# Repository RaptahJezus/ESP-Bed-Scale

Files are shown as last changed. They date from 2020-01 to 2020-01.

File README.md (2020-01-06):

ESP Powered Bed Occupancy Sensor

Uses HX711 chip and 4 load cells 

[Load Cells + HX711](https://www.ebay.com/itm/4pcs-50KG-Body-Load-Cell-Resistance-Strain-Weight-Sensor-HX711-AD-Module/182899653153)

Note: Load cells require a bracket that supports the edge, while allowing the middle portion to deflect. Included is "half_bridge_load_sensor_holder-original.stl" which can be 3D printed. I used ABS plastic for mine and it works well.

Load cell bracket design courtesy of linorics on [Thingverse](https://www.thingiverse.com/thing:2486831).

Set up WiFi and MQTT settings in Firmware/include/config.h. Example file is included

Programmed using VSCode + PlatformIO. Schematic designed in EagleCAD

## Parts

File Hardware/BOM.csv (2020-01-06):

Qty | Value | Part Num | Package | Parts
2 |  | * | B3F-10XX | PROG, RES
1 |  | * | ESP8266-ESP12E | MDL1
1 |  | * | 1X02 | VIN
1 |  | * | 1X05 | PANEL
1 | 1uF | * | C0805 | C3
6 | 10K | * | R0805 | R1, R2, R3, R4, R5, R7
1 | 10uF | * | C0805 | C5
1 | 100uf | * | C0805 | C1
1 | 100uf | * | E2,5-6E | C2
2 | 220 | * | R0805 | R8, R9
1 | 470 | * | R0805 | R6
1 | 470pF | * | C0805 | C4
1 | FTDI | * | 1X06 | JP6
1 | HX711-BREAKOUT | * | HX711-THT | U3
1 | LL | * | 1X03 | JP4
1 | LR | * | 1X03 | JP5
1 | MMBT3906 | * | TO92D | Q1
1 | SPX3819M5-L-3-3 | * | SOT23-5L | U2
1 | UL | * | 1X03 | JP2
1 | UR | * | 1X03 | JP3

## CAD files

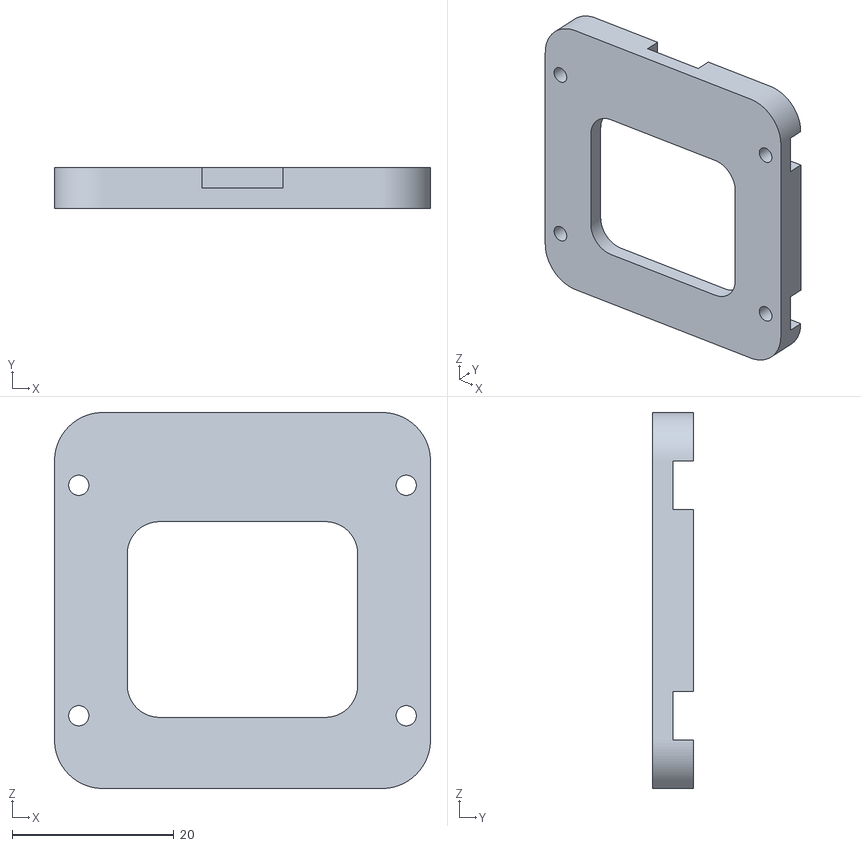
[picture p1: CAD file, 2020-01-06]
Hardware/half_bridge_load_sensor_holder-original.stl
46.5 x 5.04 x 46.5

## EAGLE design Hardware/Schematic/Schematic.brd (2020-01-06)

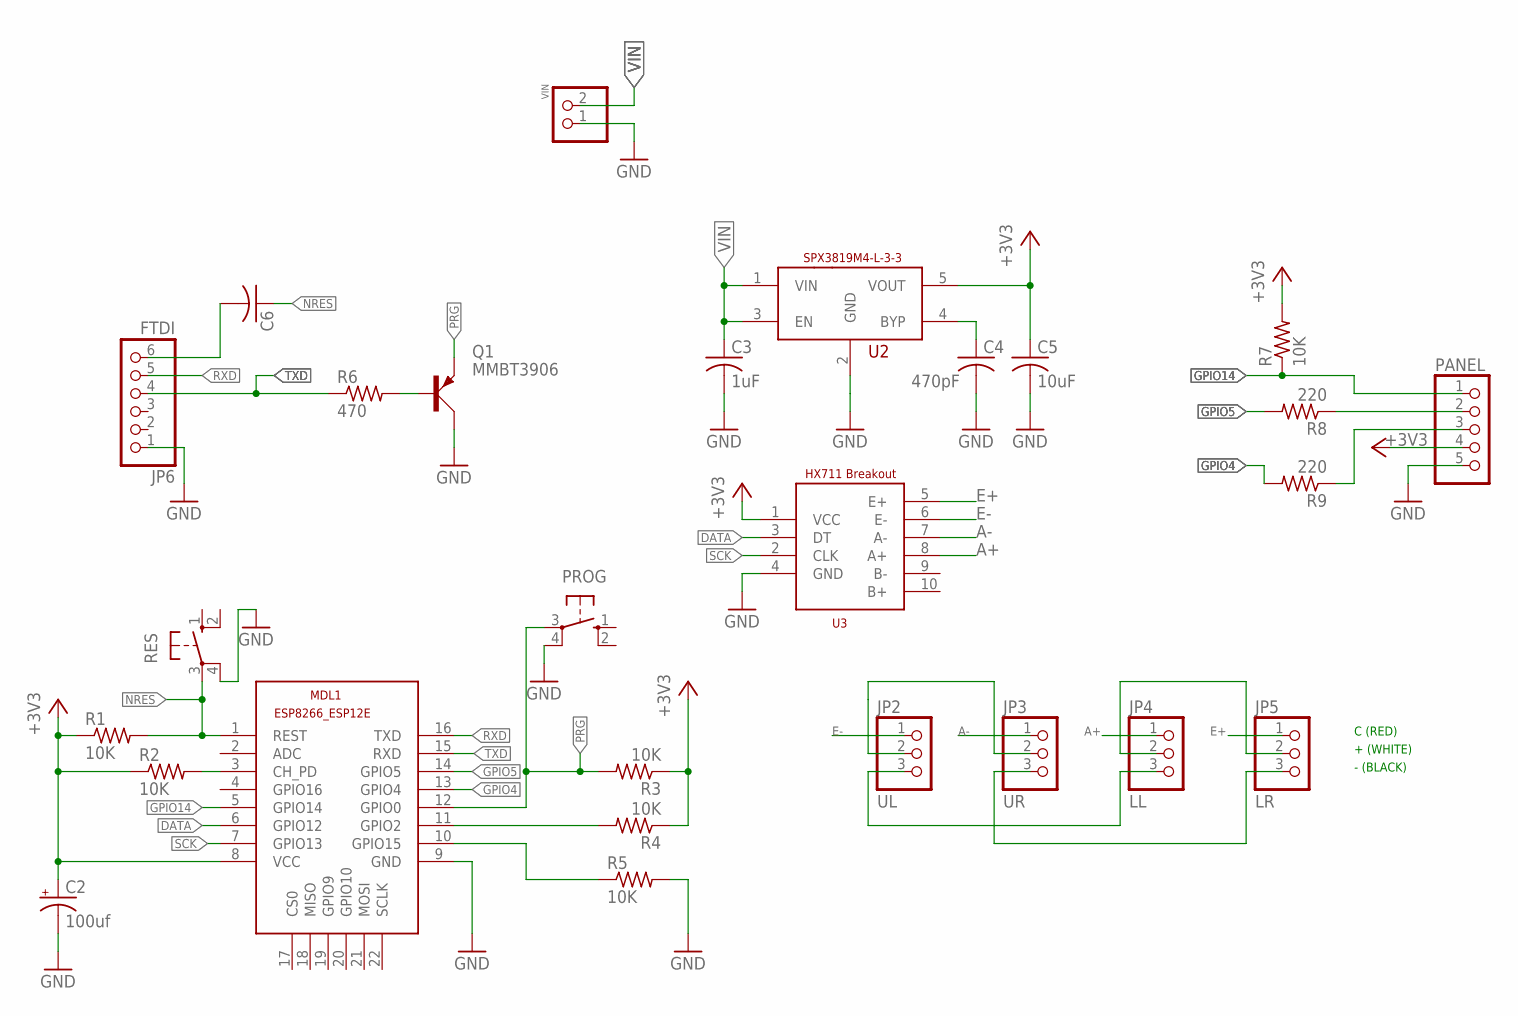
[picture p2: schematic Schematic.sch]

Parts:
C2: 100uf; E2,5-6E
C3: 1uF; C0805
C4: 470pF; C0805
C5: 10uF; C0805
C6: 100uF; C025-024X044
JP2: UL; 1X03
JP3: UR; 1X03
JP4: LL; 1X03
JP5: LR; 1X03
JP6: FTDI; 1X06
MDL1: ESP8266-12EESP8266-ESP12E; ESP8266-ESP12E
PANEL: PINHD-1X5; 1X05
PROG: 10-XX; B3F-10XX
Q1: MMBT3906; TO92D
R1, R2, R3, R4, R5, R7: 10K; R0805
R6: 470; R0805
R8, R9: 220; R0805
RES: 10-XX; B3F-10XX
U2: SPX3819M5-L-3-3; SOT23-5L
U3: HX711-BREAKOUT; HX711-THT
VIN: PINHD-1X2; 1X02

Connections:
+3V3: C2.+, C5.1, MDL1.8 (VCC), PANEL.4, R1.1, R2.1, R3.1, R4.1, R7.2, U2.5 (VOUT), U3.1 (VCC)
A+: JP4.1, U3.8 (A+)
A-: JP3.1, U3.7 (A-)
DATA: MDL1.6 (GPIO12), U3.3 (DT)
DTR: C6.2, JP6.6
E+: JP5.1, U3.5 (E+)
E-: JP2.1, U3.6 (E-)
GND: C2.-, C3.2, C4.2, C5.2, JP6.1, MDL1.9 (GND), PANEL.5, PROG.4 (P1), Q1.C, R5.2, RES.4 (P1), U2.2 (GND), U3.4 (GND), VIN.1
GPIO4: MDL1.13 (GPIO4), R9.2
GPIO5: MDL1.14 (GPIO5), R8.2
GPIO14: MDL1.5 (GPIO14), PANEL.1, R7.1
unnamed: Q1.B, R6.2
unnamed: MDL1.3 (CH_PD), R2.2
unnamed: MDL1.10 (GPIO15), R5.1
unnamed: MDL1.11 (GPIO2), R4.2
unnamed: JP2.3, JP4.3
unnamed: JP3.3, JP5.3
unnamed: JP2.2, JP3.2
unnamed: JP4.2, JP5.2
unnamed: C4.1, U2.4 (BYP)
unnamed: PANEL.2, R8.1
unnamed: PANEL.3, R9.1
NRES: C6.1, MDL1.1 (REST), R1.2, RES.3
PRG: MDL1.12 (GPIO0), PROG.3, Q1.E, R3.2
RXD: JP6.5, MDL1.16 (TXD)
SCK: MDL1.7 (GPIO13), U3.2 (CLK)
TXD: JP6.4, MDL1.15 (RXD), R6.1
VIN: C3.1, U2.1 (VIN), U2.3 (EN), VIN.2

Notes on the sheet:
C (RED)
+ (WHITE)
- (BLACK)

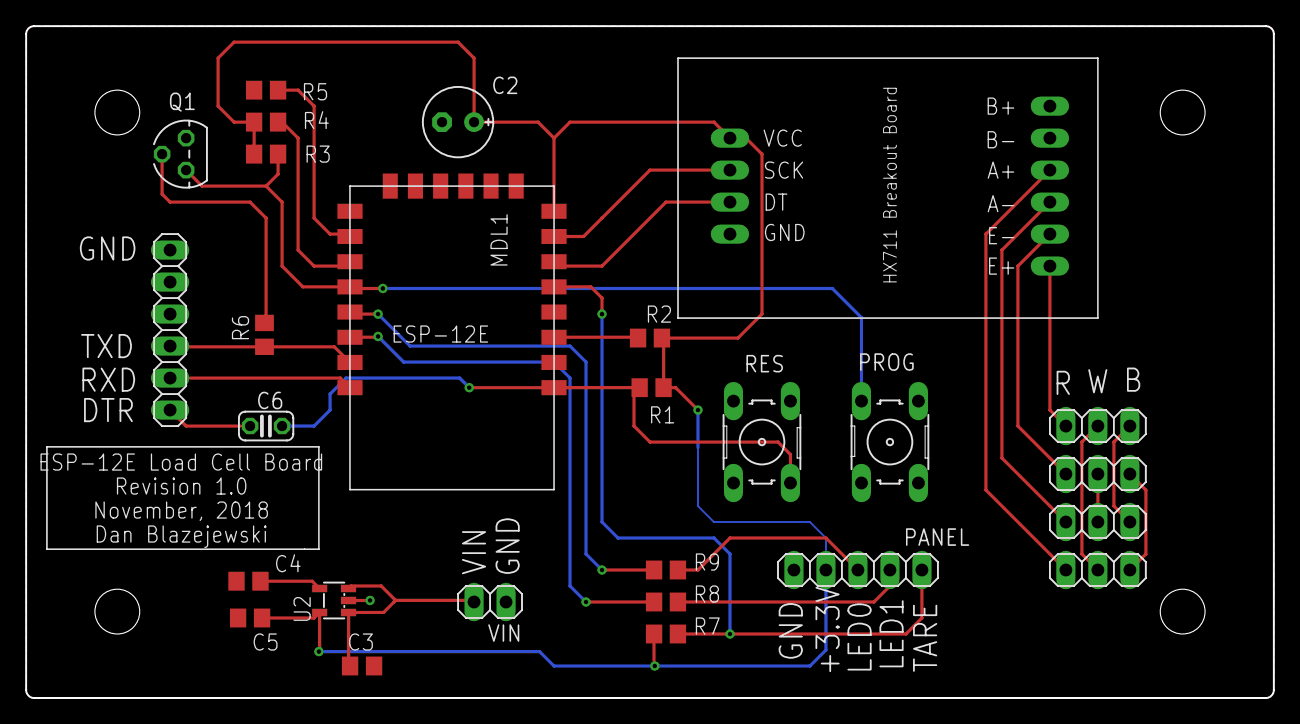
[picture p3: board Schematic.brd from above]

Board: 2 copper layers, 99.1 x 53.3 mm, 27 parts (0 on the bottom side), 28 nets.

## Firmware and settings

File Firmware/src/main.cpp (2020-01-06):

#include <Arduino.h>
#include <Wire.h>
#include "HX711.h"
#include <ESP8266WiFi.h>
#include <PubSubClient.h>
#include <ESP8266WebServer.h>
#include <ESP8266mDNS.h>
#include <ESP8266HTTPUpdateServer.h>
#include <ArduinoOTA.h>
#include "config.h"

//HX711 definitions
#define DOUT 12
#define CLK 13
#define calibration_factor 	-12850
#define NUM_SAMPLES 		3
#define SAMPLE_PERIOD 		100
#define RESULT_WIDTH 		5
#define RESOLUTION 			1
#define PRECISION 			0.1

//MQTT topics
#define TOPIC_BASE "ESP/BedScale"
#define TOPIC_MASS TOPIC_BASE "/mass"
#define TOPIC_MASS_RAW TOPIC_BASE "/massraw"
#define TOPIC_CMD  TOPIC_BASE "/cmd"
#define TOPIC_AVAIL TOPIC_BASE "/available"

//IO Definitions
int statusLED = 5;
int mqttPostLED = 4;
int tareButton = 14;

//WiFi Settings
const char* ssid = WIFI_SSID;
const char* password = WIFI_PASSWORD;

//MQTT settings
const char* mqtt_server = MQTT_SERVER_IP;
const char* mqtt_clientID = MQTT_CLIENT_ID;
const char* mqtt_username = MQTT_USER;
const char* mqtt_password = MQTT_PASSWORD;

//Variables to publish availability
static const unsigned long AVAIL_PUB_INTERVAL = 1500;
static unsigned long lastAvailPubTime = 0;

//Initiliaze scale
HX711 scale;

//Init WiFi and MQTT
WiFiClient bedScale;
PubSubClient client(bedScale);

//Init OTA functionality
ESP8266WebServer httpServer(80);
ESP8266HTTPUpdateServer httpUpdater;

void init_WiFi()
{
	delay(10);

	Serial.println();
	Serial.print("Connecting to ");
	Serial.println(ssid);

	WiFi.hostname("ESP-BedScale");
	WiFi.begin(ssid, password);

	while (WiFi.status() != WL_CONNECTED)
	{
		delay(100);
		digitalWrite(statusLED, !digitalRead(statusLED));
	}

	Serial.println("");
	Serial.println("WiFi connected.");
	Serial.print("IP Address: ");
	Serial.println(WiFi.localIP());
}


void MQTT_Reconnect()
{
	int delayCount = 0;

	while (!client.connected())
	{
		Serial.println("Attempting MQTT connection...");


		if(client.connect(mqtt_clientID, mqtt_username, mqtt_password))
		{
			Serial.println("Connected");
			client.subscribe("ESP/BedScale/cmd");
			digitalWrite(statusLED, HIGH);
		}

		else
		{
			Serial.print("failed, rc=");
			Serial.print(client.state());
			Serial.println("Trying again in 5 seconds");

			for(delayCount = 0; delayCount <= 25; delayCount++ )
			{
				digitalWrite(statusLED, !digitalRead(statusLED));
				delay(200);
			}
		}

	}
}


void callback(String topic, byte* message, unsigned int length)
{
  Serial.print("Message arrived on topic: ");
  Serial.print(topic);
  Serial.print(". Message: ");
  String messageTemp;

  for (int i = 0; i < length; i++) {
    Serial.print((char)message[i]);
    messageTemp += (char)message[i];
  }
  Serial.println();


  if(topic=="ESP/BedScale/cmd")
  {
      if(messageTemp == "tare")
      {
        Serial.println("Taring scale");
        scale.tare();
      }
    }
}


void init_OTA()
{
	MDNS.begin("ESP-BedScale");
	httpUpdater.setup(&httpServer);
	httpServer.begin();
	MDNS.addService("http","tcp",80);
	Serial.println("Http Server Ready!");


	ArduinoOTA.setPort(8266);
	ArduinoOTA.setHostname("OTA-BedScale");

	ArduinoOTA.onStart([]()
	{
		String type;
		if (ArduinoOTA.getCommand() == U_FLASH)
		{
			type = "sketch";
		}
		else // U_SPIFFS
		{
			type = "filesystem";
		}

// NOTE: if updating SPIFFS this would be the place to unmount SPIFFS using SPIFFS.end()
		Serial.println("Start updating " + type);
	});


	ArduinoOTA.onEnd([]()
	{
		Serial.println("\nEnd");
	});

	ArduinoOTA.onProgress([](unsigned int progress, unsigned int total)
	{
		Serial.printf("Progress: %u%%\r", (progress / (total / 100)));
	});

	ArduinoOTA.onError([](ota_error_t error)
	{
		Serial.printf("Error[%u]: ", error);
		if (error == OTA_AUTH_ERROR) Serial.println("Auth Failed");
		else if (error == OTA_BEGIN_ERROR) Serial.println("Begin Failed");
		else if (error == OTA_CONNECT_ERROR) Serial.println("Connect Failed");
		else if (error == OTA_RECEIVE_ERROR) Serial.println("Receive Failed");
		else if (error == OTA_END_ERROR) Serial.println("End Failed");
	});

	ArduinoOTA.begin();
}


void init_MQTT()
{
	client.setServer(mqtt_server, 1883);
	client.setCallback(callback);
}


void init_Scale()
{
	scale.begin(DOUT,CLK);
	scale.set_scale();
	scale.tare();
	scale.set_scale(calibration_factor);
}

void setup() {
  Serial.begin(9600);

  //Init functions
  init_WiFi();
  init_OTA();
  init_MQTT();
  init_Scale();

  //Configure Outputs
  pinMode(statusLED, OUTPUT);
  pinMode(mqttPostLED, OUTPUT);

}

void loop() {

	static uint32_t timer = 0;
	static uint32_t avail_timer = 0;
	static uint8_t samples = 0;
	static float avg = 0;
	static float rawavg = 0;
	static float oldAvg = 0;

	if(!digitalRead(tareButton))
	{
		Serial.println("Taring");
		scale.tare();
	}


	//Take load sample
	if(millis() - timer >= SAMPLE_PERIOD)
	{
		avg += scale.get_units();
		samples++;


		if(samples >= NUM_SAMPLES)
		{
			//Create buffer
			char result[RESULT_WIDTH + 1];
			char resultraw[RESULT_WIDTH + 1];

			//Average results
			avg /= samples;

			//Transmit only if changed
			if(abs(avg - oldAvg) > PRECISION)
			{
				rawavg = avg;
				if(avg <= 0.5)
				{
					avg = 0;
				}
				//COnvert float to string
				dtostrf(avg, RESULT_WIDTH, RESOLUTION, result);
				dtostrf(rawavg,RESULT_WIDTH, RESOLUTION, resultraw);

				//Serial.println(result);
				client.publish(TOPIC_MASS, result);
				client.publish(TOPIC_MASS_RAW, resultraw);
				digitalWrite(mqttPostLED, HIGH);
				delay(100);
				digitalWrite(mqttPostLED, LOW);
				oldAvg = avg;
			}

			Serial.println(avg);

			avg = 0;
			samples = 0;
		}

		timer = millis();
	}


	//MQTT Loop
	if(!client.connected())
	{
		MQTT_Reconnect();
	}
	client.loop();

	httpServer.handleClient();
	ArduinoOTA.handle();


	if(millis() - avail_timer >= 1500)
	{
		client.publish(TOPIC_AVAIL, "online");
		avail_timer = millis();
	}


	//Serial.println("HelloWorld");


		//Serial.println(scale.read_average());
		//Serial.print("Reading: ");
		//Serial.print(scale.get_units(), 1);
		//Serial.println(" lbs");





}
